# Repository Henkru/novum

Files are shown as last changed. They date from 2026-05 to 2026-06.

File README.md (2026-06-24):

# Novum - rev2

The split keyboard for me (it may not be for you).

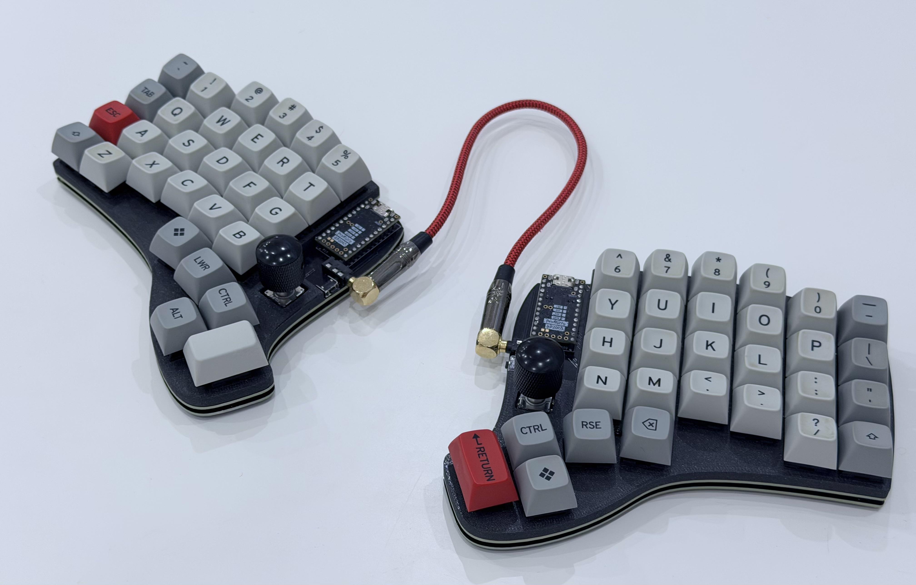
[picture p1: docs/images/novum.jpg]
Novum keyboard


If you are looking the rev1, you can find it [here](https://github.com/Henkru/novum/tree/b939535702458b90af53e7baded4479459054762).

## Background

I began my split keyboard journey with the [Lily58](https://github.com/kata0510/Lily58),
and I've been enjoying it. However, the offset of specific columns wasn't optimal
for my hands, and I couldn't comfortably reach certain keys in the thumb fan.
The [Sofle](https://josefadamcik.github.io/SofleKeyboard/) solved some of these
issues, but I decided to create my own split keyboard designed specifically for
my hands.

As part of using the Lily58, I found out:

- I didn't use the "extra" key next to G and H.
- The top left and right keys are too far away to reach.
- Swapping Ctrl and Shift keys in the default layout didn't work for me.

The following split keyboards inspire Novum:

- [Lily58](https://github.com/kata0510/Lily58)
- [Sofle](https://github.com/josefadamcik/SofleKeyboard)
- [Fortitude60](https://github.com/Pekaso/fortitude60)
- [pteron](https://github.com/FSund/pteron-keyboard)

### Design Principles

- Columns located perfectly for my fingers.
- Keep it simple and stupid:
  - No RGB nonsense
  - No display
  - No wireless
- The thumb fan is curved perfectly for my thumb, and the keys are not located under
  the hand.
- Built with [Ergogen](https://github.com/ergogen/ergogen), inspired by
  [corney-island](https://github.com/ceoloide/corney-island/tree/main) and
  [spleeb](https://github.com/chrishoage/spleeb/tree/main).
- Individual PCBs for the left and right sides. My OCD does not like the
  reversible PCBs.

## Generate PCBs

You can find the pre-generated files on the [Releases](https://github.com/Henkru/novum/releases)
page. However, if you want, you can generate the files yourself by executing the
`build.sh` script (requires [Docker](https://www.docker.com)).

The build process consists of multiple phases:

1. Generate the unrouted PCBs.
2. Inject the JLCPCB [design rules](https://github.com/labtroll/KiCad-DesignRules).
3. Import hand-routed tracks into PCBs.
4. [Autoroute](https://freerouting.org) the unconnected items.
5. Use [KiBot](https://github.com/INTI-CMNB/KiBot) to generate gerbers and images.

Each step is located in the `builder/steps` folder. Hand-routed tracks
can be extracted from the `.kicad_pcb` files by executing `npm run export-tracks`.

## Different PCBs

The revision 1 is a typical sandwich design, with each layer intended to be a
1.6 mm thick FR-4 circuit board. This approach reduces costs and streamlines
manufacturing, as it allows all boards to be ordered from a single supplier.

The current design offers three variants for the bottom board. The _standard_
version features intricate PCB art on exposed copper layers and requires an
[ENIG](https://jlcpcb.com/blog/203-choosing-the-right-surface-finish-for-your-pcb/?from=BWBS)
(Electroless Nickel Immersion Gold) surface finish. If this design feels too
elaborate, a blank bottom board is also included in the release package as an
alternative. Additionally, the package contains a bottom board compatible with
splitkb's [tenting puck](https://splitkb.com/products/tenting-puck) accessary,
providing further customization options.

| Top side | Bottom side |
| --- | --- |
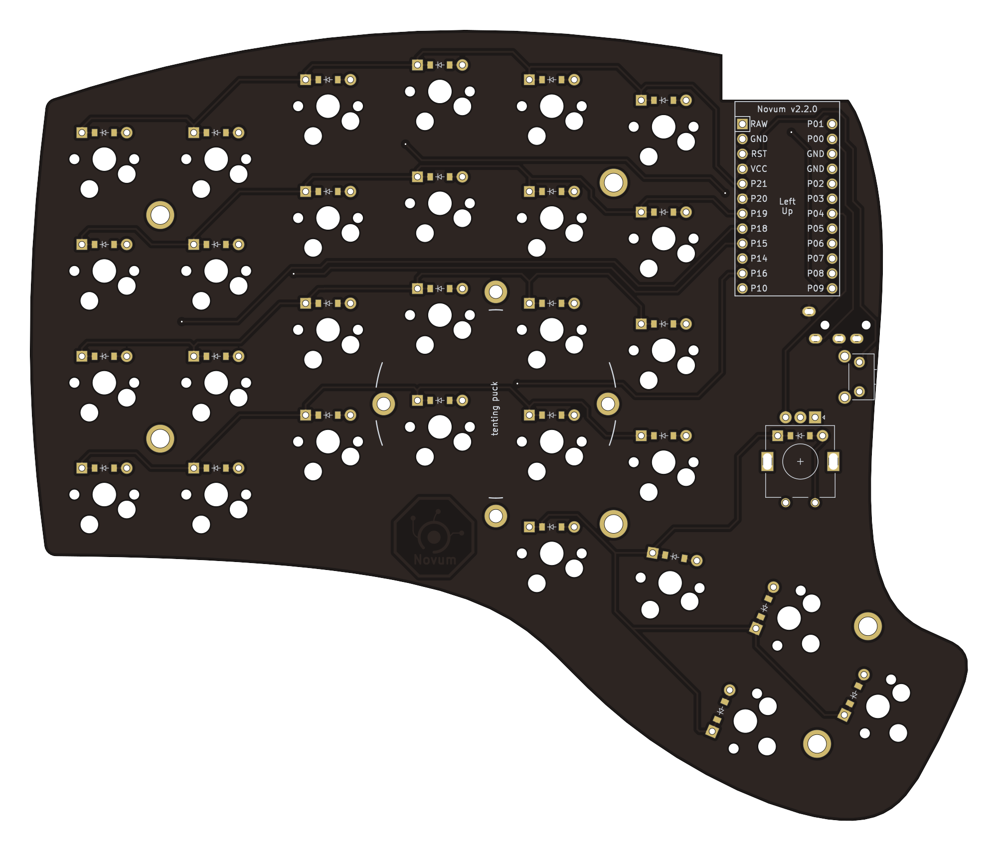
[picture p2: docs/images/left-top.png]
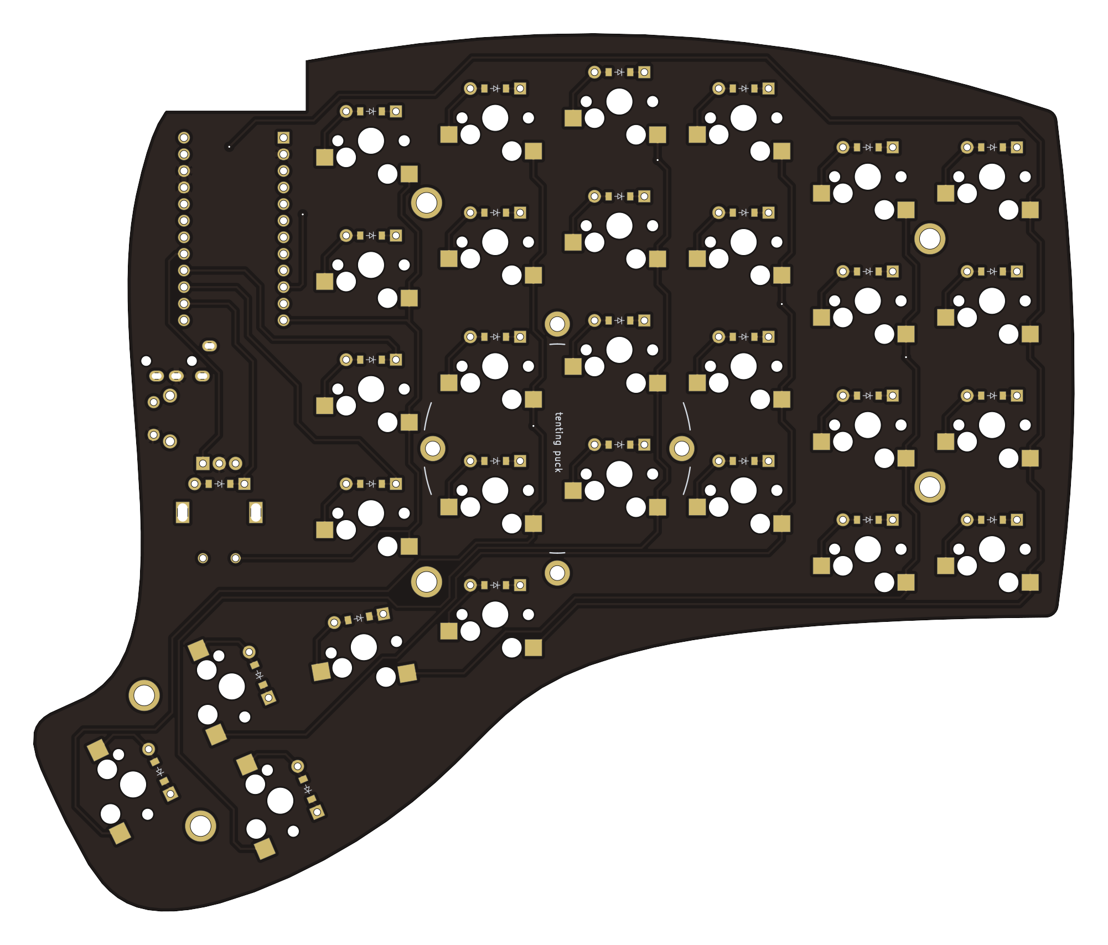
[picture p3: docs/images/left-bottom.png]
|  |  |
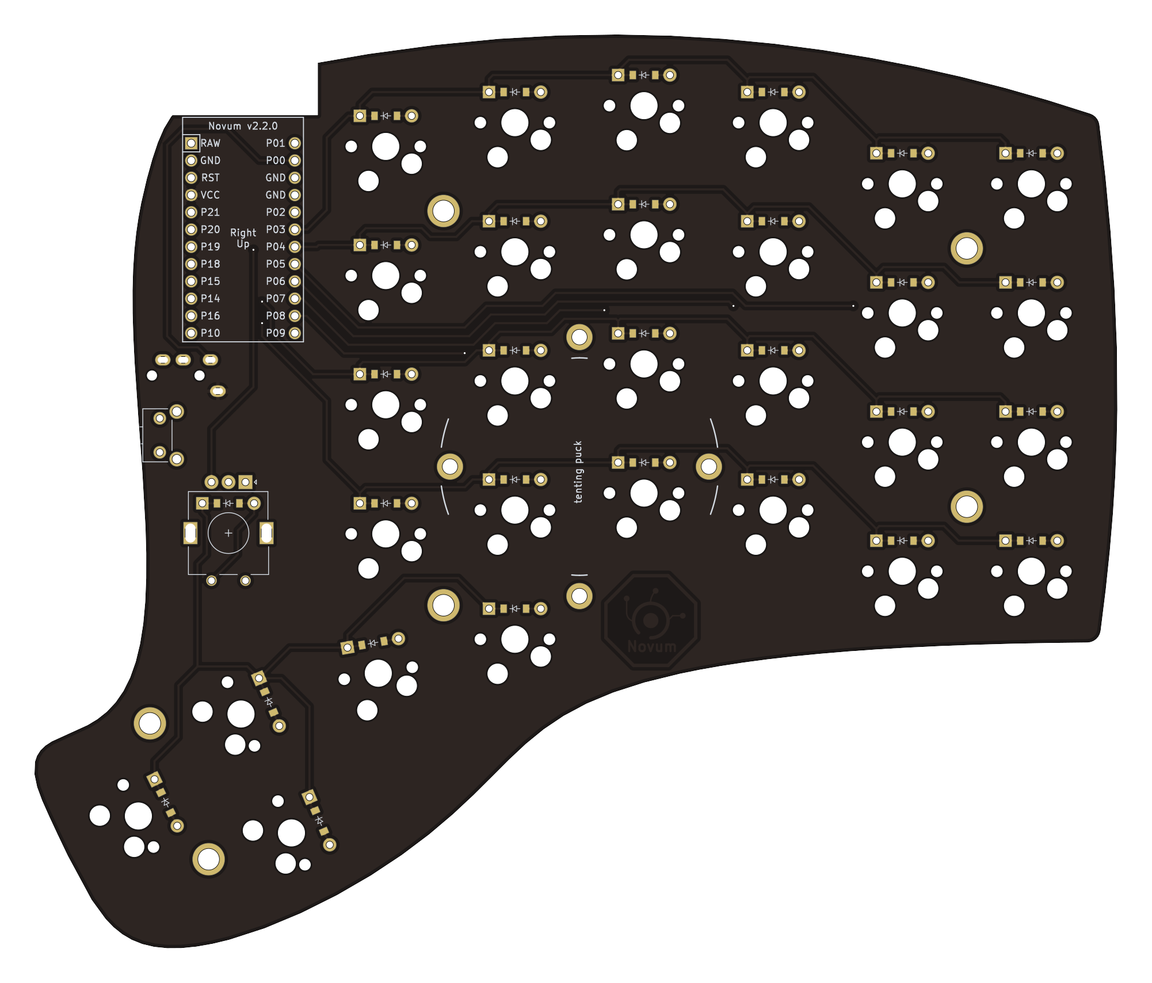
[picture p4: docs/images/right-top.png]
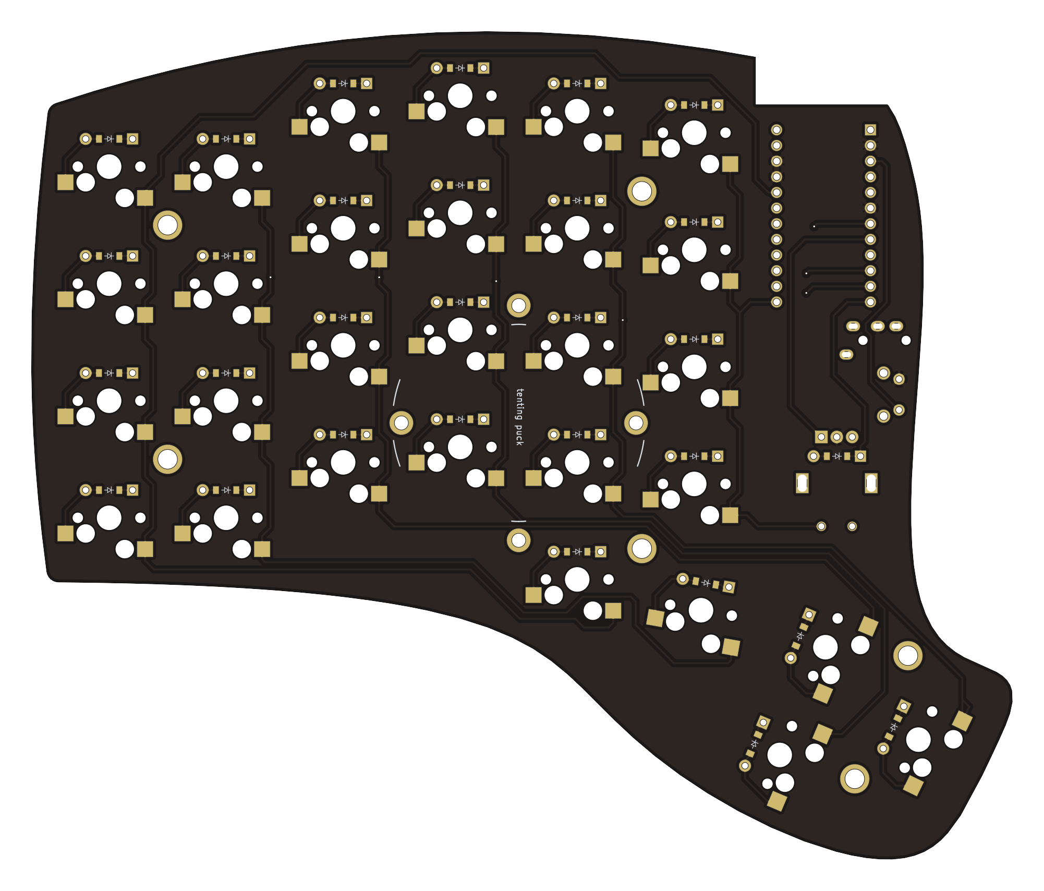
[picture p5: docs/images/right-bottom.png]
|  |  |
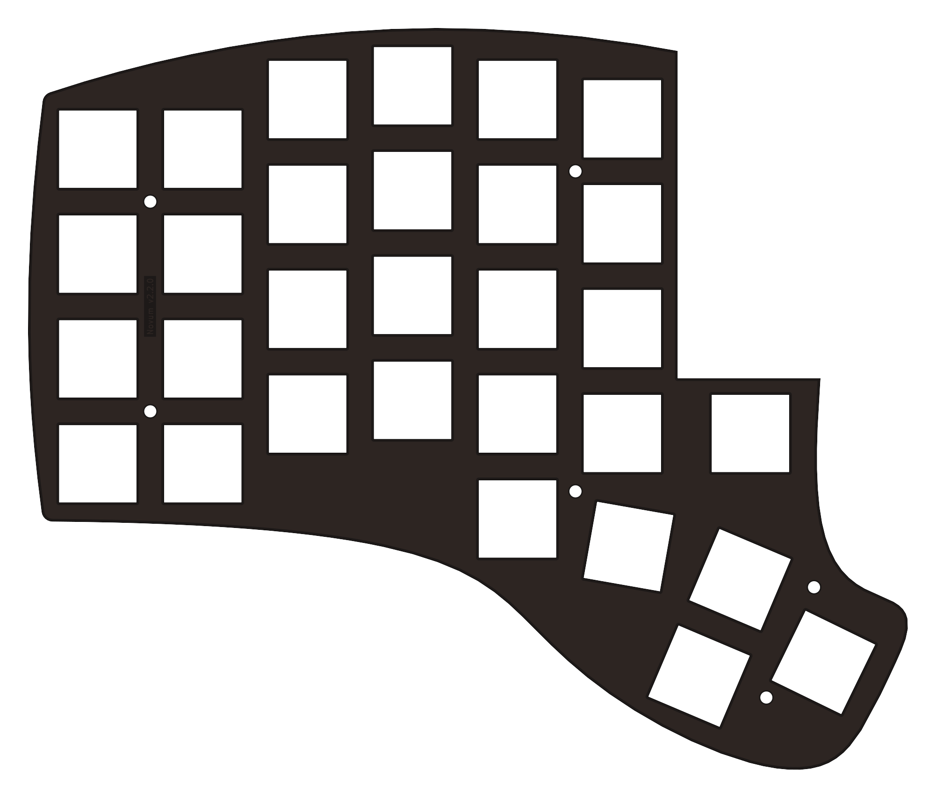
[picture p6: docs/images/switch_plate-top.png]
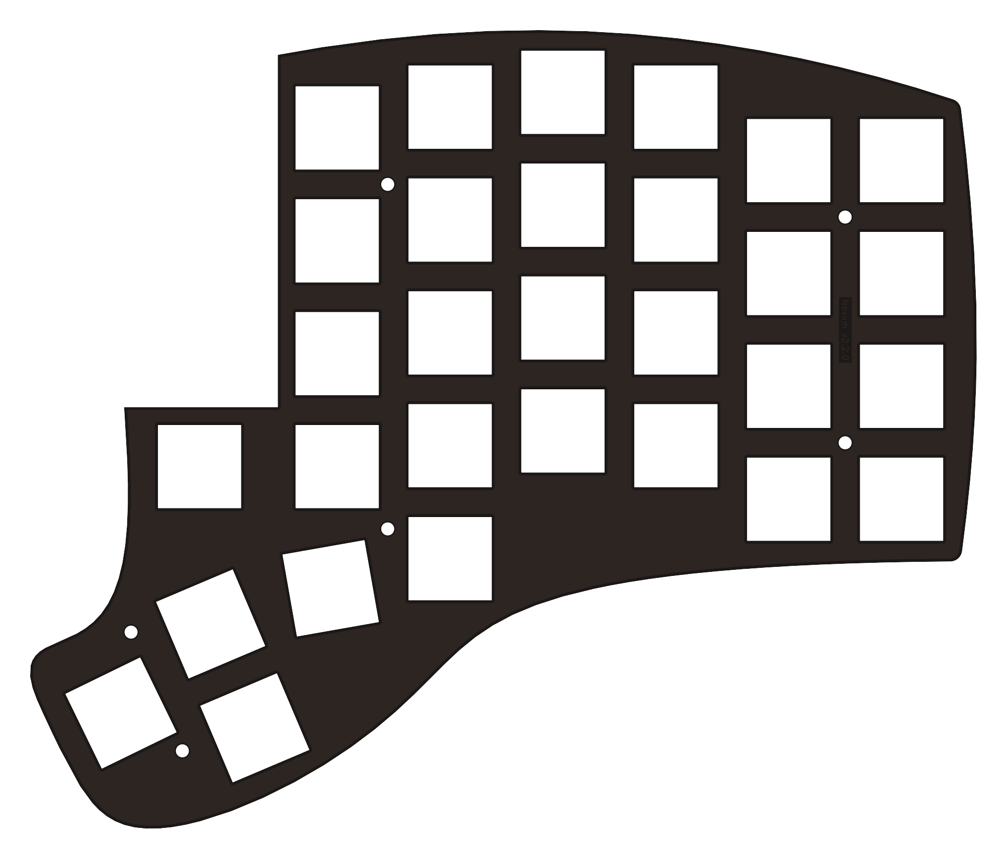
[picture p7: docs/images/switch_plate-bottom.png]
|  |  |
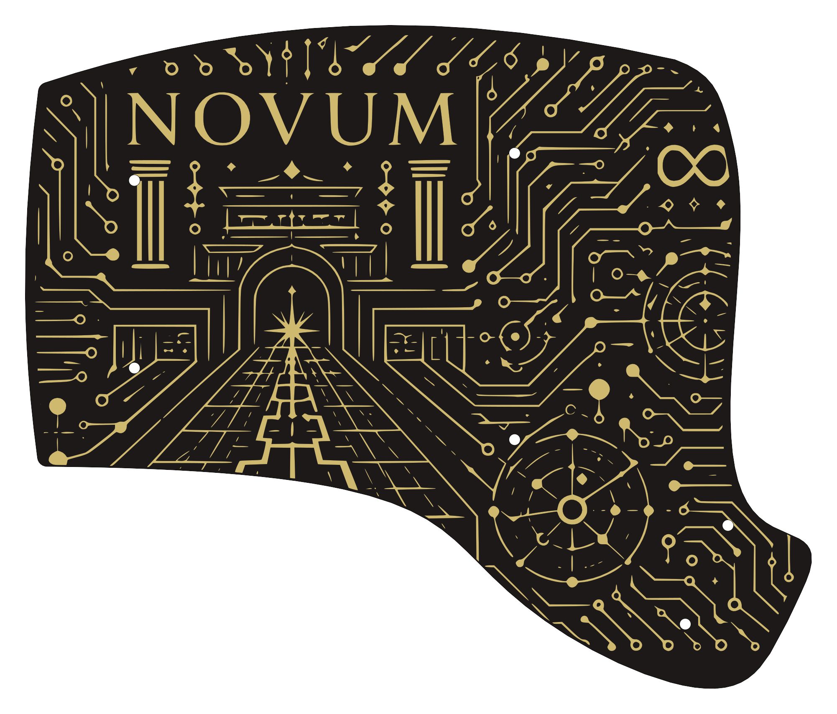
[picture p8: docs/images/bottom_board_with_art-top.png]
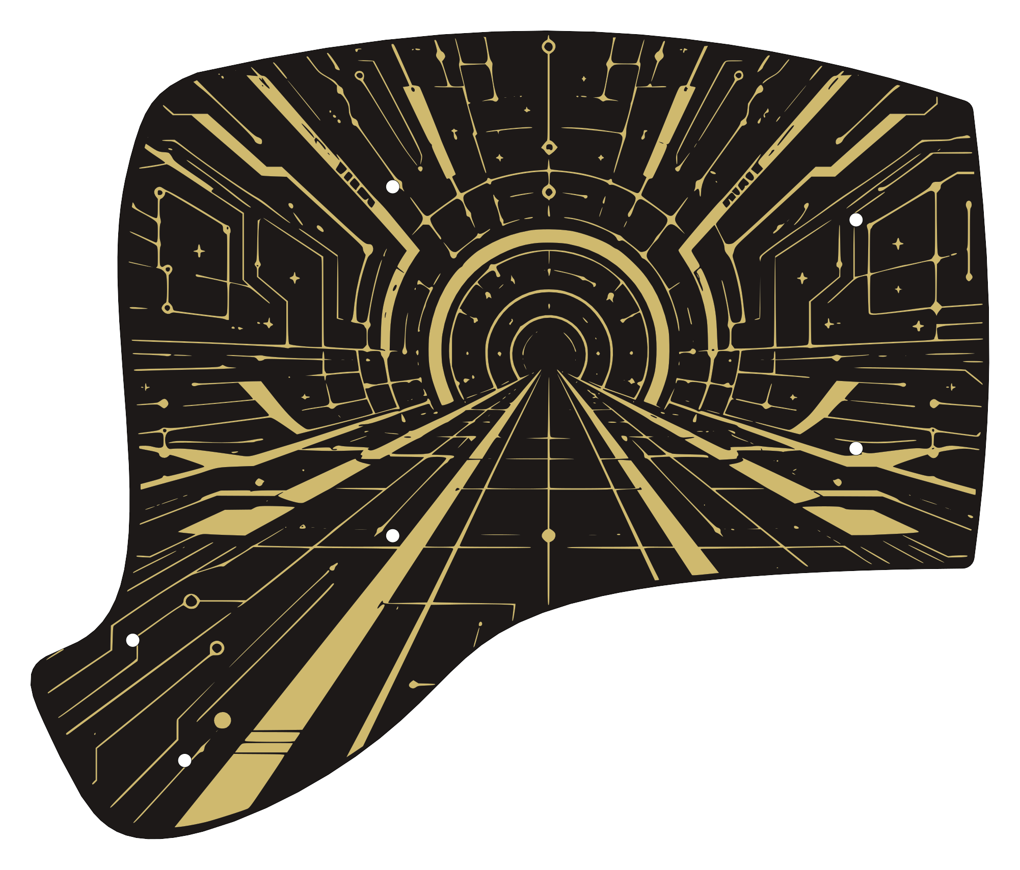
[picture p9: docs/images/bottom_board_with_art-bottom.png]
|  |  |
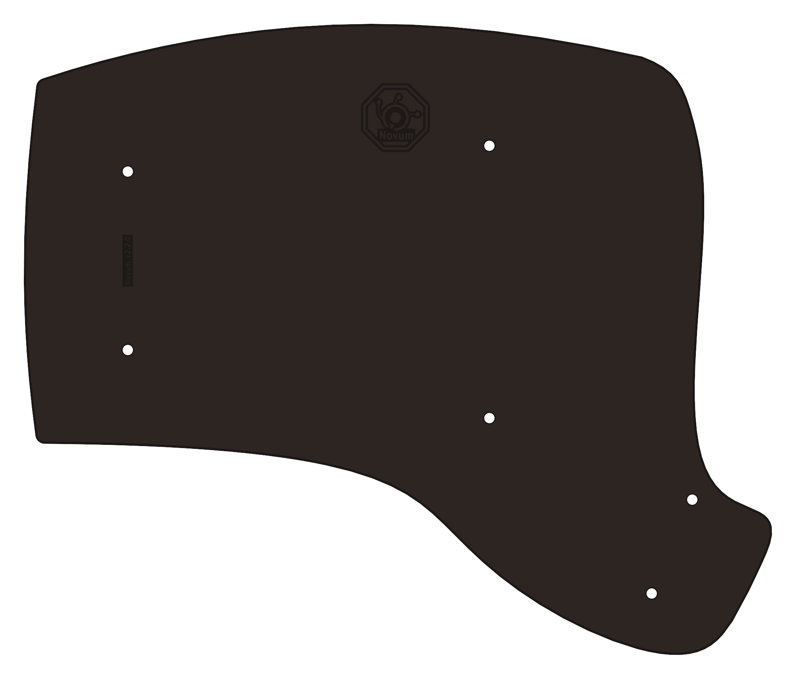
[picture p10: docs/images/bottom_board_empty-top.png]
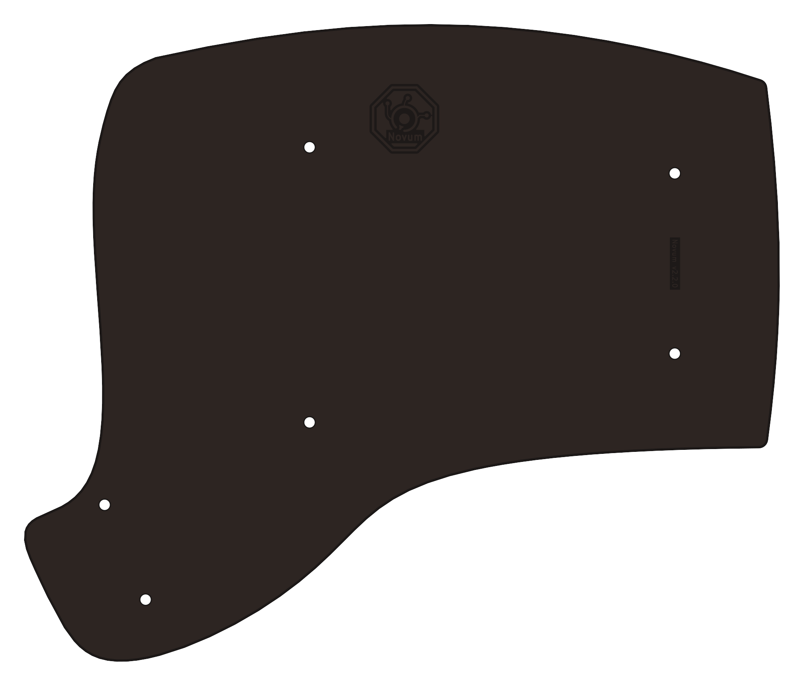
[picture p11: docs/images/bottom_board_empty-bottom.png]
|  |  |
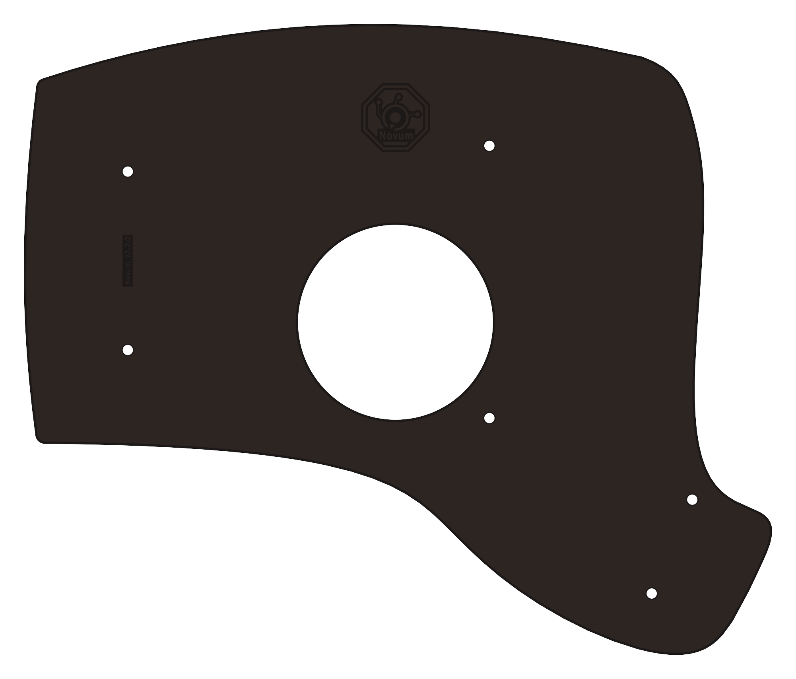
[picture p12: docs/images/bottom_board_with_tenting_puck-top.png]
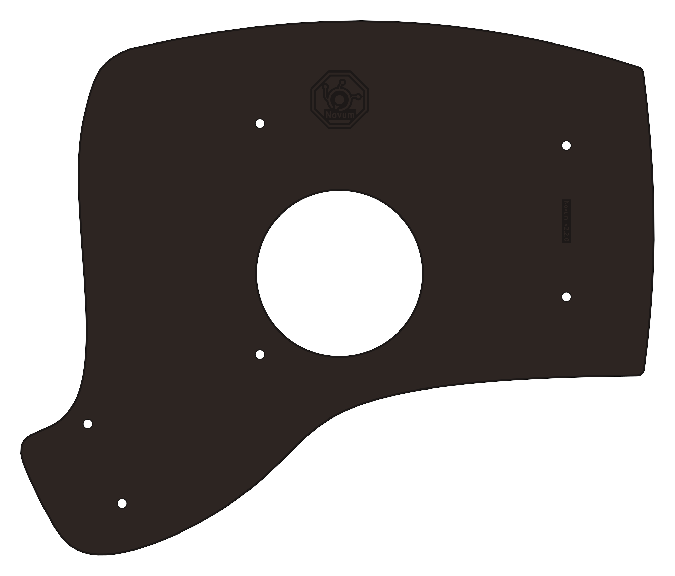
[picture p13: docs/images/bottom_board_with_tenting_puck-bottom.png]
|  |  |

## BOM

| Item | Quantity | Notes |
| --- | --- | --- |
| Novum Left PCB | 1 | |
| Novum Right PCB | 1 | |
| Novum Switch Plate | 2 | |
| Novum Bottom Plate | 2 | Three different version available, see [images](https://github.com/Henkru/novum/tree/main/docs/images) |
| [1N4148W Diode](https://www.lcsc.com/product-detail/Switching-Diodes_Jiangsu-Changjing-Electronics-Technology-Co-Ltd-1N4148W_C2099.html) | 60 | SOD-123 or through hole |
| [Kailh Hot-Swap Socket](https://www.lcsc.com/product-detail/Mechanical-Keyboard-Shaft_Kailh-CPG151101S11-16_C5156480.html) | 58 | |
| [RP2040 Community Edition](https://github.com/qmk/qmk_firmware/blob/master/docs/platformdev_rp2040.md) MCU Board | 2 | |
| [PJ-320A TRRS Jack](https://www.lcsc.com/product-detail/Audio-Connectors-Headphones_XKB-Connection-PJ-320A_C2884926.html) | 2 | |
| [SKHLLCA010 Button](https://www.lcsc.com/product-detail/Tactile-Switches_ALPSALPINE-SKHLLCA010_C139766.html) | 2 | |
| [EC11 Encoder](https://www.lcsc.com/product-detail/Rotary-Encoders_ALPSALPINE-EC11E183440C_C370986.html) | 2 | |
| M2 x 4 mm screw | 24 | |
| M2 x 8 mm spacer | 12 | Outer diameter: 3.1 mm |

## Firmware

Any [RP2040 Community Edition](https://github.com/qmk/qmk_firmware/blob/master/docs/platformdev_rp2040.md)
standard boards should. However, the keyboard is only tested with [Liatris](https://splitkb.com/products/liatris)
and [SparkFun Pro Micro - RP2040](https://www.sparkfun.com/products/18288) boards.
The following firmware is currently supported, and the pre-build binaries can
be found on the [Releases](https://github.com/Henkru/novum/releases) page.

- [QMK](https://github.com/qmk/qmk_firmware)
- [Vial](https://github.com/vial-kb/vial-qmk)

Currently, the keyboard has yet to be merged into the above mainline repos.

## Default Layout

The default layout for the keyboard

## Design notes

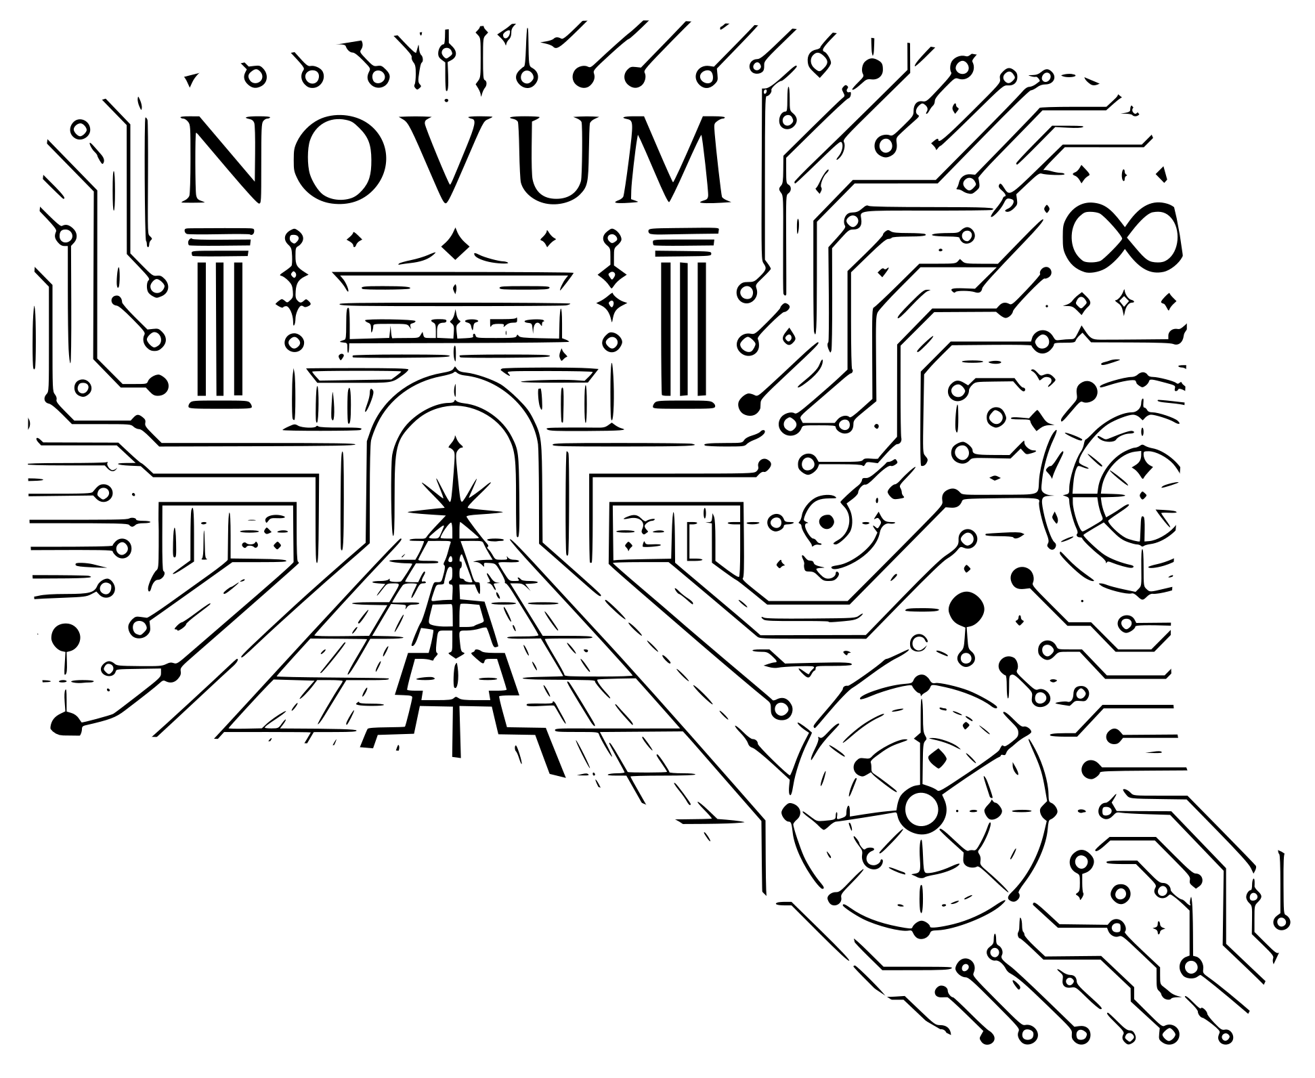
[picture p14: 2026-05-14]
novum/art/top.png

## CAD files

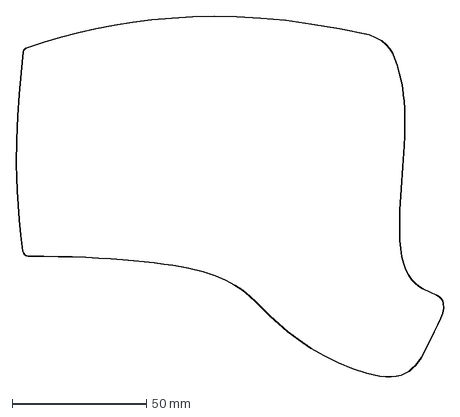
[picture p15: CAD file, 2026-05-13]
novum/outline/left.dxf
159.3 x 134.4 mm

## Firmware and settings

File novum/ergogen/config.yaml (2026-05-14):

meta:
  engine: 4.1.0
  version: 2.0.0
  author: Henri Nurmi
units:
  kx: u
  ky: u
  px: kx + 2
  py: ky + 2
  mirror_distance: 10U
  index_stagger: -2.5
  arch_top_x: 0
  arch_top_y: -132.5
  arch_bottom_x: -70
  arch_bottom_y: -323
  arch_left_x: 230.5
  arch_left_y: 16
  arch_right_x: -224
  arch_right_y: 20
  mcu_shift_x: kx + 2
  mcu_shift_y: -13.5
  conn_cut_width: 22
  conn_cut_shift_y: 9.6
  mounting_spacer_diameter: 3.1
  mounting_hole_diameter: 2.2
  trrs_shift_x: kx + 17
  trrs_shift_y: mcu_shift_y - 22.5
  reset_shift_x: kx + 13
  reset_shfit_y: trrs_shift_y - 6.5
  tenting_puck_shift_y: -ky/2 - 5.6
  logo_shift_y: -16.25
  zone_width: 10kx
  zone_height: 8ky
points:
  zones:
    matrix:
      key.tags: switch
      columns:
        outer:
          key.column_net: COL0
        pinky:
          key.column_net: COL1
        ring:
          key.stagger: 9
          key.column_net: COL2
        middle:
          key.stagger: 2.5
          key.column_net: COL3
        index:
          key.stagger: index_stagger
          key.column_net: COL4
        inner:
          key.stagger: -3.5
          key.column_net: COL5
      rows:
        bottom:
          row_net: ROW3
        home:
          row_net: ROW2
        top:
          row_net: ROW1
        num:
          row_net: ROW0
      # Fix placement on KiCAD sheet.
      anchor:
        shift: [50, -100]
    thumbs:
      key.tags: switch
      anchor:
        ref: matrix_index_bottom
        shift: [0, -ky]
      columns:
        mod1:
          key.column_net: COL0
          rows:
            cluster:
              row_net: ROW4
        mod2:
          key:
            shift: [1.1, -5]
            rotate: -10
          key.column_net: COL1
          rows:
            cluster:
              row_net: ROW4
        layer:
          rows:
            layer:
              shift: [2.3, -11]
              rotate: 67
              padding: 0
              column_net: COL2
              row_net: ROW4
              name: thumbs_layer_cluster
            mod3:
              shift: [-kx, 0]
              column_net: COL3
              row_net: ROW4
              name: thumbs_mod3_cluster
        space:
          key:
            width: 1.5kx
            rotate: 64
            shift: [-1.6, -26]
          key.column_net: COL4
          rows:
            cluster:
              row_net: ROW4
    encoder:
      key.tags: encoder
      anchor:
        ref: matrix_inner_bottom
        shift: [1.22kx, 0]
      columns:
        col:
          key.column_net: COL5
      rows:
        row:
          row_net: ROW4
    mounting_left:
      key:
        tags: mount
        padding: 2ky
      anchor:
        ref: matrix_outer_bottom
        shift: [kx/2, ky/2]
      columns:
        c1:
      rows:
        r1:
        r2:
    mounting_right:
      key:
        tags: mount
        padding: 3ky + 1
      anchor:
        ref: matrix_inner_bottom
        shift: [-kx/2 + 1, -ky/2 - 1]
      columns:
        c1:
      rows:
        r1:
        r2:
    mounting_thumb:
      key:
        tags: mount
      anchor:
        ref: thumbs_space_cluster
        shift: [kx/2 + 2, ky/2 - 2]
      columns:
        c1:
      rows:
        r1:
    mounting_space_left_bottom:
      key:
        tags: mount
      anchor:
        ref: thumbs_space_cluster
        shift: [-0.75kx + 4, -0.5ky + 16]
      columns:
        c1:
      rows:
        r1:
  mirror:
    ref: matrix_middle_bottom
    distance: mirror_distance
outlines:
  _keys_normal:
    - what: rectangle
      where: [switch, encoder]
      size: [kx-1, ky-1]
  _keys_space:
    - what: rectangle
      where:
        ref: thumbs_space_cluster
      size: [1.5kx-1, ky-1]
  keys:
    - name: _keys_normal
    - operation: stack
      name: _keys_space
  # Outline arches for left side
  _top_arch_circle_left:
    - what: circle
      radius: 200
      where:
        ref: matrix_middle_bottom
        shift: [arch_top_x, arch_top_y]
  _bottom_arch_circle_left:
    - what: circle
      radius: 300
      where:
        ref: matrix_middle_bottom
        shift: [arch_bottom_x, arch_bottom_y]
  _left_arch_circle_left:
    - what: circle
      radius: 300
      where:
        ref: matrix_middle_bottom
        shift: [arch_left_x, arch_left_y]
  _right_arch_circle_left:
    - what: circle
      radius: 300
      where:
        ref: matrix_middle_bottom
        shift: [arch_right_x, arch_right_y]
  _conn_cut_left:
    - what: rectangle
      size: [conn_cut_width, 10]
      where:
        ref: matrix_inner_num
        shift: [kx + 2, conn_cut_shift_y]
  _arches_left:
    [
      +_top_arch_circle_left,
      -_bottom_arch_circle_left,
      ~_left_arch_circle_left,
      ~_right_arch_circle_left,
    ]
  # Outline arches for right side
  _top_arch_circle_right:
    - what: circle
      radius: 200
      where:
        ref: matrix_middle_bottom
        shift: [mirror_distance - arch_top_x, arch_top_y]
  _bottom_arch_circle_right:
    - what: circle
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

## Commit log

2026-05-13 feat(pcbs): rev 2 pcbs
    [left.dxf]
2026-05-14 feat(pcbs): update artwork
2026-05-14 feat(ci): exclude switch-plate without mcu-cutout
2026-05-14 feat(pcbs): update tracks
2026-05-14 feat(pcbs): move logo
2026-05-15 📦 v2.0.0 [release]
2026-06-24 📦 v2.1.0 [release]
2026-06-24 📦 v2.2.0 [release]
